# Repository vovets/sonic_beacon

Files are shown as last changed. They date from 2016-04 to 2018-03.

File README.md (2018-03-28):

# Sonic Beacon

## Overview
This little device is supposed to provide an aid in finding small RC models in the grass or other obstacles. It does so by emitting series of loud beeps. It was originally designed to be used with Blade series of micro helicopters but can be used with any model that has throttle signal.

## Operating conditions
| Parameter | Value(s) |
| --- | --- |
| Input Voltage | 3...16 V |
| Input Signal Type | PWM >500 Hz or Standard Servo PWM 1500 uS center, <500Hz |
| Throttle Threshold PWM | 1/8 (12.5%) duty cycle |
| Throttle Threshold Servo | 1248 uS (25% of full throttle) |
## Modes of operation
Device has two modes of operation: auxiliary "calibration" which will be discussed later and main "normal".

## Theory of operation ("normal" mode)
1. Device gets powered on and automatically detects control signal type be it standard servo signal or PWM.
1. Device waits for the control signal to be higher than threshold value for more than 3 seconds then device becomes "armed".
1. Device waits for the control signal to be lower than threshold value for more than 30 seconds then device starts emitting series of tones and does so indefinitely.

## Practice of operation ("normal" mode)
1. Operator powers up model.
1. Operator starts flying model. To do so he pushes the throttle up, so throttle gets higher than the threshold. In 3 seconds beacon arms and emits two tones.
1. In the unfortunate event that the model can not be sighted after landing because of grass or other obstacles operator zeroes the throttle (or failsafe does so). After 30 seconds beacon starts emitting beeps and that aids operator in locating model ~~crash~~landing site.

## Connections
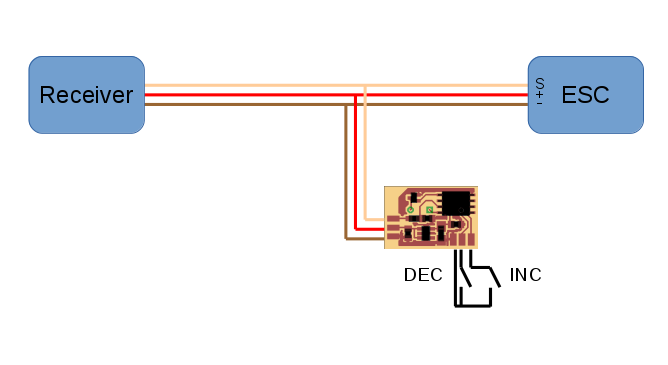
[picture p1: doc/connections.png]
Connection diagram


## Tone frequency calibration ("calibration" mode)
The frequency of the tone emitted by the device can be adjusted by user to accommodate for differences in hearing or variations in device base frequency. Adjusted frequency is stored in device's eeprom so it is not lost after power off.

Device pcb has two special pads for this purpose designated as **DEC** and **INC** in schematics and silk layer.
To adjust frequency it is needed to solder buttons from these pad to **GND** pad or use piece of wire or metallic tweezers or something similar. In the following we will refer to them as buttons for brevity.

To enter calibration mode **DEC** button must be pressed upon powering device on. Device starts emitting continuous tone. Frequency of the tone can be adjusted by pressing **INC** or **DEC** buttons. Adjusted frequency gets immediately stored in the eeprom. To exit this mode device needs to be powered off.

## Good practice
It is highly recommeded that after installation on the model device undergoes full functionality test. **_Any propellers and blades must be removed from the model before starting any tests._**

## Implementation details

### Directory structure
```
.
├── doc          - schematics in pdf, images
├── board        - schematics, board, library for Eagle
│   └── output   - Eagle output: pdf, tiff, etc.
└── firmware     - software sources for IAR Embedded Workbench
    ├── Release  - compiler output, ignored by git
    │   ├── Exe  - flash.hex (flash.bin) is a file you are looking For
    │   ├── List
    │   └── Obj
    └── settings - IAR settings, ignored by git
```

### Schematics in pdf
[Here.](doc/sonic_beacon.pdf)

### Components
* MCU - ATtiny85-20, as firmware size is under 4k so ATtiny45-20 should also do. Uses 8 MHz internal RC clock which provides for stable operation at as low as 2.7V.
* Voltage Regulator - TI LP2981-33 ultra-low dropout. Provides 3-16V working voltage range.

### Fuses

```
SELFPRGEN = [ ]
RSTDISBL = [ ]
DWEN = [ ]
SPIEN = [X]
WDTON = [ ]
EESAVE = [X]
BODLEVEL = 1V8
CKDIV8 = [ ]
CKOUT = [ ]
SUT_CKSEL = INTRCOSC_8MHZ_6CK_14CK_64MS

EXTENDED = 0xFF
HIGH = 0xD6
LOW = 0xE2
```

### Places of interest in source files
1. [Where the throttle threshold is defined for PWM signal?](https://github.com/vovets/sonic_beacon/blob/433788d3e038b642e70308b3990e0a55145812b6/firmware/sonic_beacon.c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)
1. [Where the throttle threshold is defined for Servo signal?](https://github.com/vovets/sonic_beacon/blob/433788d3e038b642e70308b3990e0a55145812b6/firmware/signal_detection.c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)

### Software versions
Software versions with which board and firmware were developed.
1. Eagle 7.5 or 7.7
1. IAR Embedded Workbench 6.8

### Cheap hardware/sofware for firmware flashing
* [usbasp](http://www.fischl.de/usbasp/) - under $5 usb device for flashing AVR MCUs. Can be found on ebay, aliexpress, banggood and even hobbyking. 
* [avrdude](https://www.nongnu.org/avrdude/) - command line software for flashing AVR MCUs. There are versions for Windows and GUI tools available.

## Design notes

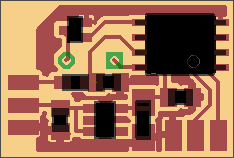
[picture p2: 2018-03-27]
doc/pcb_top.png

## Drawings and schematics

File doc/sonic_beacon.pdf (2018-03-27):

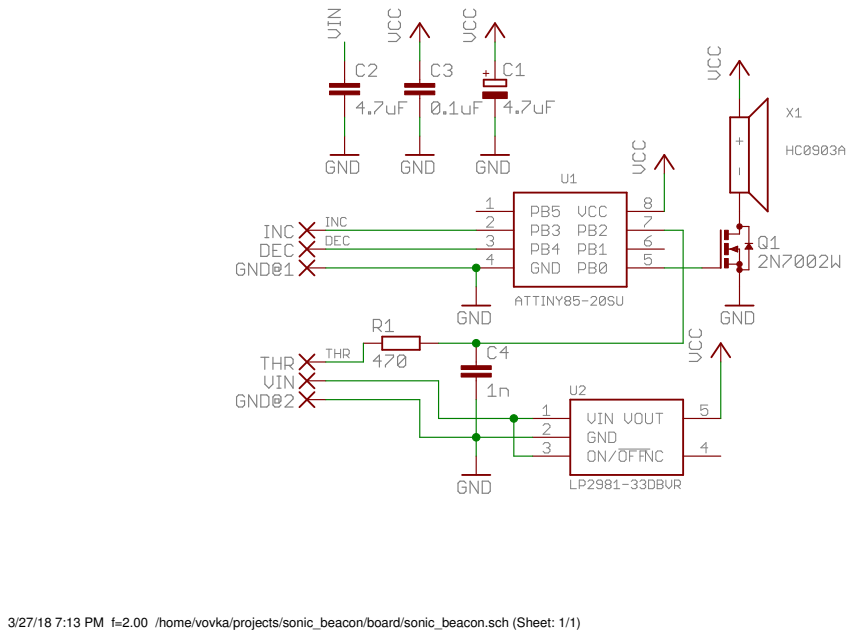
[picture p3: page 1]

3/27/18 7:13 PM f=2.00 /home/vovka/projects/sonic_beacon/board/sonic_beacon.sch (Sheet: 1/1)

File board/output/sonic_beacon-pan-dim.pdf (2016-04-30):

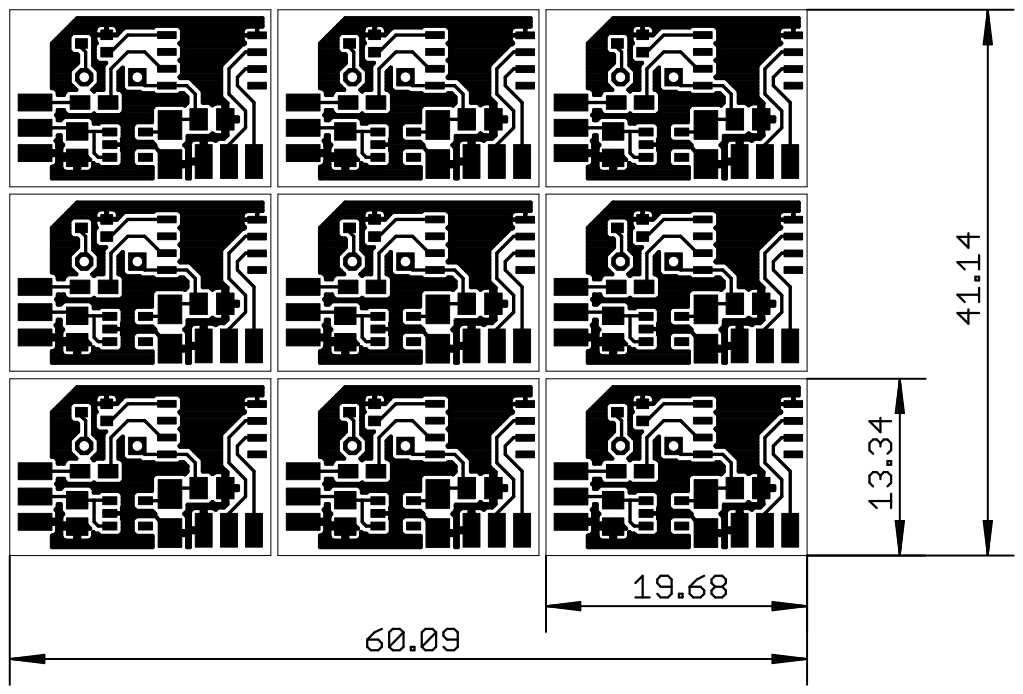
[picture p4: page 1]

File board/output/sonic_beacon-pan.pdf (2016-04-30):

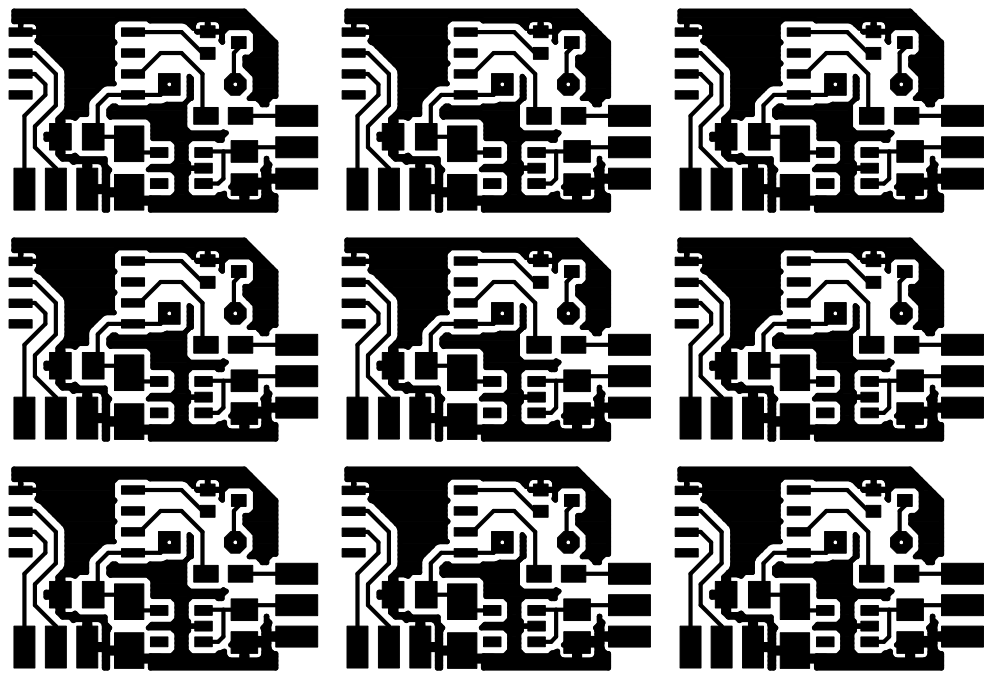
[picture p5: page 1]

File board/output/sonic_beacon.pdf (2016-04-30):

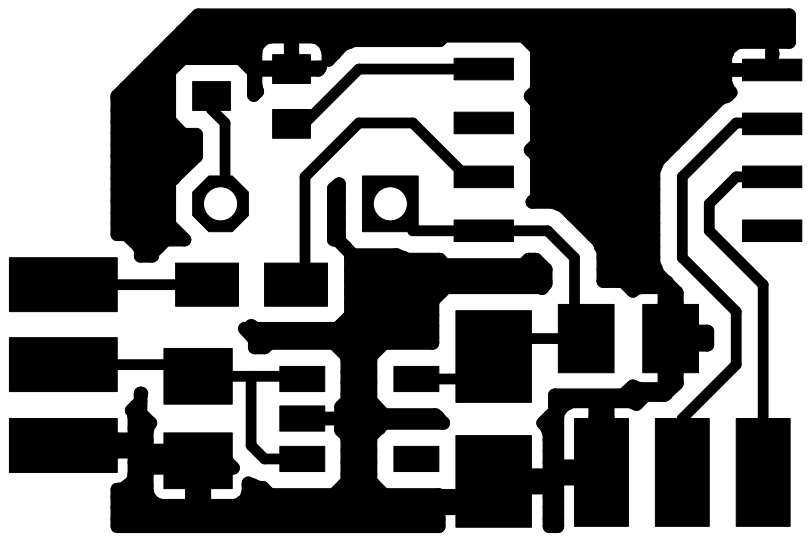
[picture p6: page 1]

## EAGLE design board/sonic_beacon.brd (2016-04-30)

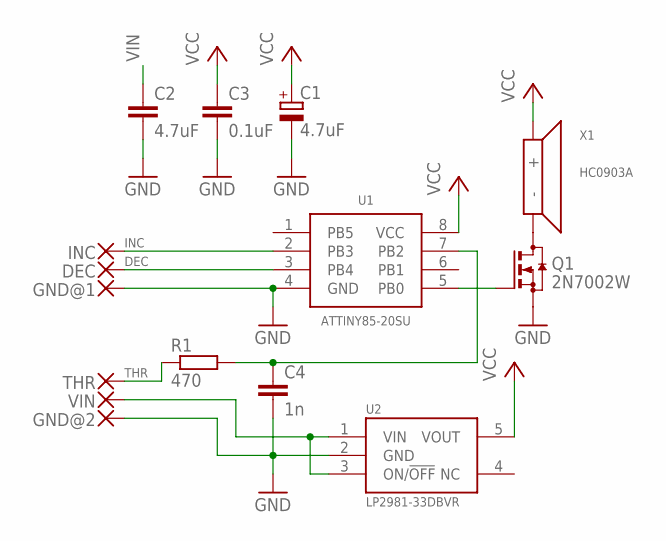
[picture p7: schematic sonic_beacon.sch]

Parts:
C1: 4.7uF; A/3216-18W
C2: 4.7uF; C0805K
C3: 0.1uF; C0805K
C4: 1n; C0805K
DEC: WIREPAD; PAD
GND@1, GND@2: WIREPAD; PAD
INC: WIREPAD; PAD
Q1: 2N7002W; SC-70
R1: 470; R0805W
THR: WIREPAD; PAD
U1: ATTINY85-20SU; 8S2
U2: LP2981-33DBVR; SOT-23
VIN: WIREPAD; PAD
X1: HC0903A

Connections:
DEC: DEC.P$1, U1.3 (PB4)
GND: C1.-, C2.2, C3.2, C4.2, GND@1.P$1, GND@2.P$1, Q1.2 (S), U1.4 (GND), U2.2 (GND)
INC: INC.P$1, U1.2 (PB3)
unnamed: Q1.1 (G), U1.5 (PB0)
unnamed: Q1.3 (D), X1.2 (-)
unnamed: U2.1 (VIN), U2.3 (ON/!OFF), VIN.P$1
unnamed: C4.1, R1.2, U1.7 (PB2)
THR: R1.1, THR.P$1
VCC: C1.+, C3.1, U1.8 (VCC), U2.5 (VOUT), X1.1 (+)
VIN: C2.1

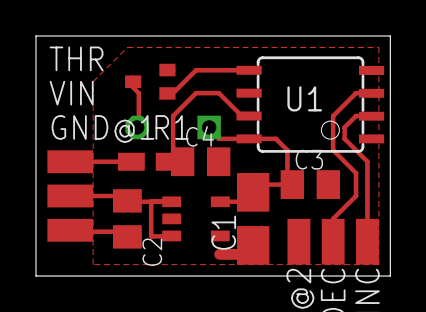
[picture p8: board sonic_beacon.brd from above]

Board: 2 copper layers, 19.7 x 13.3 mm, 15 parts (1 on the bottom side), 9 nets.

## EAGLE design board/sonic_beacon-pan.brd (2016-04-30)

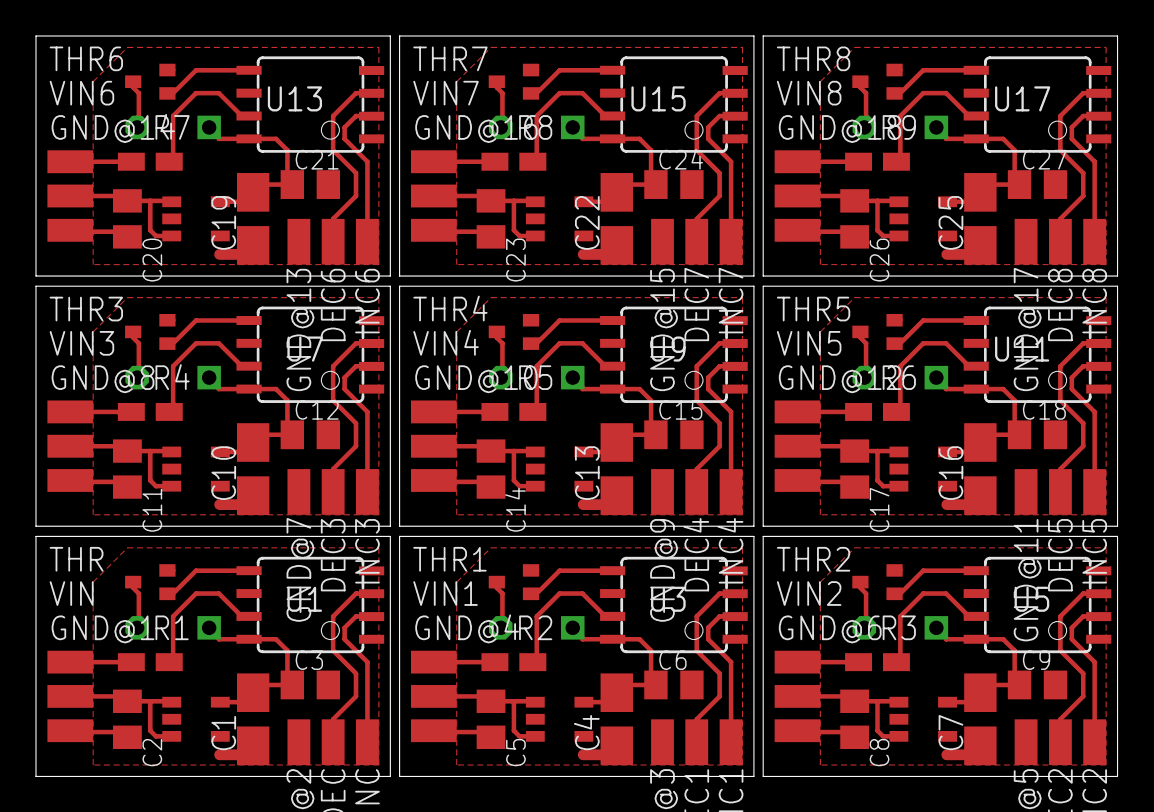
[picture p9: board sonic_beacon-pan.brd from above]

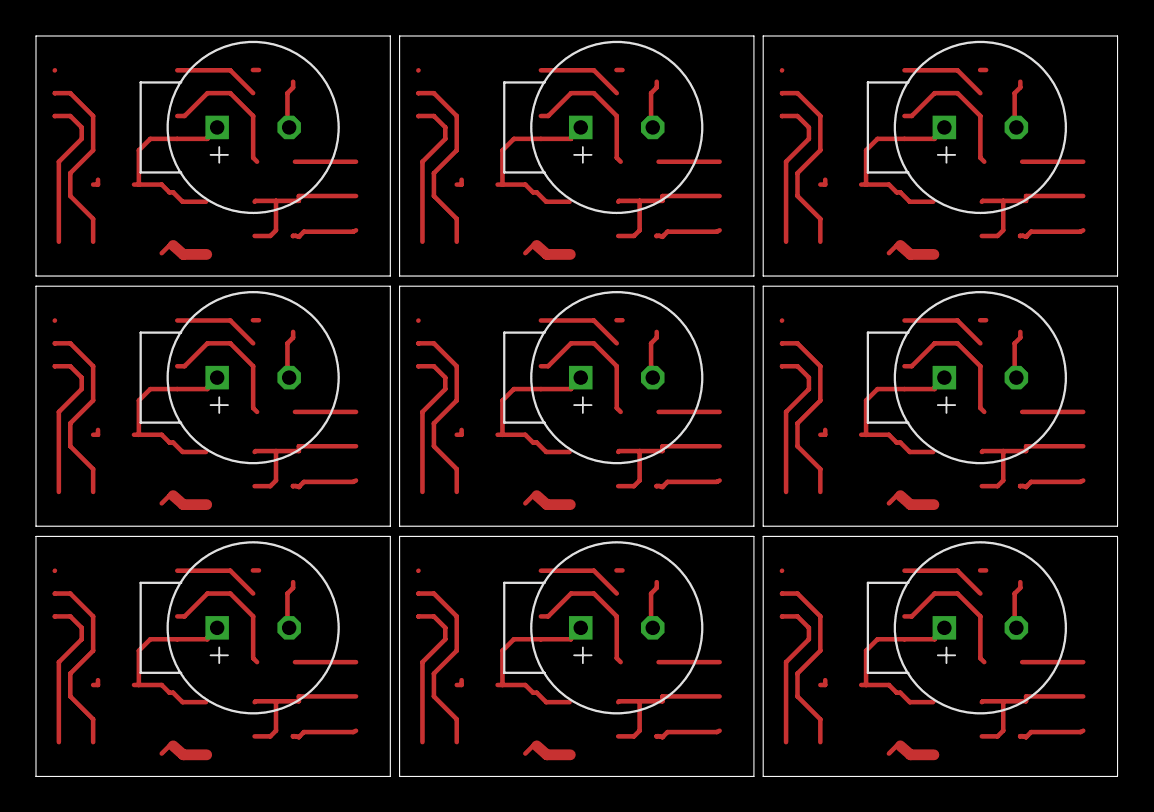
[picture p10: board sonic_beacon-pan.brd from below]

Board: 2 copper layers, 60.1 x 41.1 mm, 126 parts (9 on the bottom side), 81 nets.

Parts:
C1, C4, C7, C10, C13, C16, C19, C22, C25: 4.7uF; A/3216-18W
C2, C5, C8, C11, C14, C17, C20, C23, C26: 4.7uF; C0805K
C3, C6, C9, C12, C15, C18, C21, C24, C27: 0.1uF; C0805K
DEC, DEC1, DEC2, DEC3, DEC4, DEC5, DEC6, DEC7, DEC8: PAD
GND@1, GND@2, GND@3, GND@4, GND@5, GND@6, GND@7, GND@8, GND@9, GND@10, GND@11, GND@12, GND@13, GND@14, GND@15, GND@16, GND@17, GND@18: PAD
INC, INC1, INC2, INC3, INC4, INC5, INC6, INC7, INC8: PAD
Q1, Q2, Q3, Q4, Q5, Q6, Q7, Q8, Q9: 2N7002W; SC-70
R1, R2, R3, R4, R5, R6, R7, R8, R9: 100; R0805W
THR, THR1, THR2, THR3, THR4, THR5, THR6, THR7, THR8: PAD
U1, U3, U5, U7, U9, U11, U13, U15, U17: ATTINY85-20SU; 8S2
U2, U4, U6, U8, U10, U12, U14, U16, U18: LP2981-33DBVR; SOT-23
VIN, VIN1, VIN2, VIN3, VIN4, VIN5, VIN6, VIN7, VIN8: PAD
X1, X2, X3, X4, X5, X6, X7, X8, X9: HC0903A

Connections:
DEC: DEC.P$1, U1.3
DEC1: DEC1.P$1, U3.3
DEC2: DEC2.P$1, U5.3
DEC3: DEC3.P$1, U7.3
DEC4: DEC4.P$1, U9.3
DEC5: DEC5.P$1, U11.3
DEC6: DEC6.P$1, U13.3
DEC7: DEC7.P$1, U15.3
DEC8: DEC8.P$1, U17.3
GND: C1.-, C2.2, C3.2, GND@1.P$1, GND@2.P$1, Q1.2, U1.4, U2.2
GND1: C4.-, C5.2, C6.2, GND@3.P$1, GND@4.P$1, Q2.2, U3.4, U4.2
GND2: C7.-, C8.2, C9.2, GND@5.P$1, GND@6.P$1, Q3.2, U5.4, U6.2
GND3: C10.-, C11.2, C12.2, GND@7.P$1, GND@8.P$1, Q4.2, U7.4, U8.2
GND4: C13.-, C14.2, C15.2, GND@9.P$1, GND@10.P$1, Q5.2, U9.4, U10.2
GND5: C16.-, C17.2, C18.2, GND@11.P$1, GND@12.P$1, Q6.2, U11.4, U12.2
GND6: C19.-, C20.2, C21.2, GND@13.P$1, GND@14.P$1, Q7.2, U13.4, U14.2
GND7: C22.-, C23.2, C24.2, GND@15.P$1, GND@16.P$1, Q8.2, U15.4, U16.2
GND8: C25.-, C26.2, C27.2, GND@17.P$1, GND@18.P$1, Q9.2, U17.4, U18.2
INC: INC.P$1, U1.2
INC1: INC1.P$1, U3.2
INC2: INC2.P$1, U5.2
INC3: INC3.P$1, U7.2
INC4: INC4.P$1, U9.2
INC5: INC5.P$1, U11.2
INC6: INC6.P$1, U13.2
INC7: INC7.P$1, U15.2
INC8: INC8.P$1, U17.2
unnamed: Q1.1, U1.5
unnamed: Q1.3, X1.2
unnamed: Q2.1, U3.5
unnamed: R1.2, U1.7
unnamed: Q2.3, X2.2
unnamed: R2.2, U3.7
unnamed: Q3.1, U5.5
unnamed: Q3.3, X3.2
unnamed: R3.2, U5.7
unnamed: Q4.1, U7.5
unnamed: Q4.3, X4.2
unnamed: R4.2, U7.7
unnamed: Q5.1, U9.5
unnamed: Q5.3, X5.2
unnamed: R5.2, U9.7
unnamed: Q6.1, U11.5
unnamed: Q6.3, X6.2
unnamed: R6.2, U11.7
unnamed: Q7.1, U13.5
unnamed: Q7.3, X7.2
unnamed: R7.2, U13.7
unnamed: Q8.1, U15.5
unnamed: Q8.3, X8.2
unnamed: R8.2, U15.7
unnamed: Q9.1, U17.5
unnamed: Q9.3, X9.2
unnamed: R9.2, U17.7
THR: R1.1, THR.P$1
THR1: R2.1, THR1.P$1
THR2: R3.1, THR2.P$1
THR3: R4.1, THR3.P$1
THR4: R5.1, THR4.P$1
THR5: R6.1, THR5.P$1
THR6: R7.1, THR6.P$1
THR7: R8.1, THR7.P$1
THR8: R9.1, THR8.P$1
VCC: C1.+, C3.1, U1.8, U2.5, X1.1
VCC1: C4.+, C6.1, U3.8, U4.5, X2.1
VCC2: C7.+, C9.1, U5.8, U6.5, X3.1
VCC3: C10.+, C12.1, U7.8, U8.5, X4.1
VCC4: C13.+, C15.1, U9.8, U10.5, X5.1
VCC5: C16.+, C18.1, U11.8, U12.5, X6.1
VCC6: C19.+, C21.1, U13.8, U14.5, X7.1
VCC7: C22.+, C24.1, U15.8, U16.5, X8.1
VCC8: C25.+, C27.1, U17.8, U18.5, X9.1
VIN: C2.1, U2.1, U2.3, VIN.P$1
VIN1: C5.1, U4.1, U4.3, VIN1.P$1
VIN2: C8.1, U6.1, U6.3, VIN2.P$1
VIN3: C11.1, U8.1, U8.3, VIN3.P$1
VIN4: C14.1, U10.1, U10.3, VIN4.P$1
VIN5: C17.1, U12.1, U12.3, VIN5.P$1
VIN6: C20.1, U14.1, U14.3, VIN6.P$1
VIN7: C23.1, U16.1, U16.3, VIN7.P$1
VIN8: C26.1, U18.1, U18.3, VIN8.P$1

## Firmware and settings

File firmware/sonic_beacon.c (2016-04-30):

#include "frequency_detection.h"
#include "signal_detection.h"
#include "timeout_timer.h"
#include "music.h"
#include "pin_defs.h"
#include "delay.h"
#include "pwm.h"
#include "eeprom.h"

#include <intrinsics.h>
#include <ioavr.h>

#define TIMEOUT_PERIODS(MS) (((MS) * 1000L) / TT_1_PERIOD_US);

static const uint16_t armTimeout = TIMEOUT_PERIODS(3000);
static const uint16_t alarmTimeout = TIMEOUT_PERIODS(30000);

static int8_t freqDelta = 0;

static const muCommandT alarm[] = {
    { muTone, 100 },
    { muPause, 50 },
    { muTone, 100 },
    { muPause, 50 },
    { muTone, 100 },
    { muPause, 50 },
    { muTone, 100 },
    { muPause, 1000 }};

static const muCommandT armed[] = {
    { muTone, 100 },
    { muPause, 50 },
    { muTone, 100 },
    { muStop, 0 }
};


typedef enum EventT {
    eventOn,
    eventOff,
    eventTimeout
} Event;

static Event event;
static uint8_t eventReady = 0;

static void signalCallback(SdSignalState state) {
    switch (state) {
    case sdOn:
        event = eventOn;
        break;
    case sdOff:
        event = eventOff;
        break;
    default:
        ;
    }
    eventReady = 1;
}

static void timeoutCallback(void) {
    event = eventTimeout;
    eventReady = 1;
}

static Event waitForEvent(void) {
    while (!eventReady) {
        __no_operation();
    }
    Event e = event;
    eventReady = 0;
    return e;
}

int normal(void) {
    __enable_interrupt();
    InParams result;
    fdDetectFrq(&result);
    uint16_t period_uS = (1 << (result.prescaler - 4)) * result.counter;
    if (period_uS < 2000) {
        if (result.counter > 253) {
            result.counter /= 2;
            ++result.prescaler;
        }
        SdParams sdParams;
        sdParams.prescaler = result.prescaler;
        sdParams.T0 = result.counter / 8;
        sdParams.Tovf = result.counter + 2;
        sdStartSignalDetector(&sdParams, signalCallback);
    } else {
        sdStartSignalDetectorServo(signalCallback);
    }
    for (uint8_t stop = 0; !stop;) {
        switch (waitForEvent()) {
        case eventOn:
            ttStart(armTimeout, timeoutCallback);
            break;
        case eventOff:
            ttStop();
            break;
        case eventTimeout:
            ttStop();
            stop = 1;
            break;
        default:
            ;
        }
    }
    __disable_interrupt();
    muPlay(armed, sizeof(armed) / sizeof(armed[0]), freqDelta);
    __enable_interrupt();
    for (uint8_t stop = 0; !stop;) {
        switch (waitForEvent()) {
        case eventOn:
            ttStop();
            break;
        case eventOff:
            ttStart(alarmTimeout, timeoutCallback);
            break;
        case eventTimeout:
            ttStop();
            stop = 1;
            break;
        default:
            ;
        }
    }
    muPlay(alarm, sizeof(alarm) / sizeof(alarm[0]), freqDelta);
    return 0;
}

static inline int8_t max(int8_t a, int8_t b) {
    return a > b ? a : b;
}

static inline int8_t min(int8_t a, int8_t b) {
    return a < b ? a : b;
}

int calibration(void) {
    pwmStart(freqDelta, 0);
    for (uint8_t n = 5; n; n -= PIN_BUTTON_DEC) {
        delay(10);
    }
    for (;;) {
        uint8_t buttonPressed = 0;
        if (!PIN_BUTTON_DEC) {
            freqDelta = max(freqDelta - 1, -32);
            buttonPressed = 1;
        }
        if (!buttonPressed && !PIN_BUTTON_INC) {
            freqDelta = min(freqDelta + 1, 31);
            buttonPressed = 1;
        }
        if (buttonPressed) {
            pwmSet(freqDelta);
            eepStore((uint8_t)freqDelta);
            delay(150);
        }
    }
}

int main(void) {
    DDR_OUT = 1;
    PORT_OUT = 0;
    PORT_BUTTON_DEC = 1;
    PORT_BUTTON_INC = 1;
    freqDelta = (int8_t)eepLoad();
    uint8_t cal = 0;
    cal += PIN_BUTTON_DEC;
    delay(10);
    cal += PIN_BUTTON_DEC;
    delay(10);
    cal += PIN_BUTTON_DEC;
    if (!cal) {
        return calibration();
    } else {
        return normal();
    }
}

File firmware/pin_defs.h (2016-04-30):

#pragma once

#include <ioavr.h>

#define DDR_BUTTON_INC DDRB_DDB3
#define PORT_BUTTON_INC PORTB_PORTB3
#define PIN_BUTTON_INC PINB_PINB3

#define DDR_BUTTON_DEC DDRB_DDB4
#define PORT_BUTTON_DEC PORTB_PORTB4
#define PIN_BUTTON_DEC PINB_PINB4

#define DDR_IN DDRB_DDB2
#define PORT_IN PORTB_PORTB2
#define PIN_IN PINB_PINB2

// OC0A
#define DDR_OUT DDRB_DDB0
#define PORT_OUT PORTB_PORTB0
#define PIN_OUT PINB_PINB0

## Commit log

2018-03-24 don't track settings dir
2018-03-26 Added fuse values
2018-03-27 added connection diagram, schematics in pdf
2018-03-27 link to schematics in pdf
2018-03-27 added links to where throttle threshold defined in sources
